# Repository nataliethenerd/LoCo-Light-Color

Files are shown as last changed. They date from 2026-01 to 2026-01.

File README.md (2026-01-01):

# LoCo (Light Color)





LoCo = Light Color. This project allows you to put a Game Boy Color in a Game Boy Light shell. Full Light colour PCB using the original parts. This board is made with modern screen kits in mind meaning it does not have the voltage rails for the original screen.

**ORDER AT 1MM WITH ENIG**

You can support me on Ko-Fi or by buying the board directly from me [my store](https://nataliethenerd.com/collections/all)

I also occasionally sell pre built PCBs on my store.



## Building

locoboardview

> [!WARNING]
> I am not responsible for your skill issues!

This board uses all the parts of an original Game Boy Color minus the IR and original screen circuit. Most parts are in the same spot, however if you are having trouble you can check the [interactive BOM](https://nataliethenerd.github.io/loco.html)

The thumbwheel circuit can be connected to an OSD screen to control brightness. The two touch pad wires and be connected to the pads labelled ↑↓ on the back top left side of the board. The select, A and B pads are easy connection pads for the screen also. 

screenguide

**My recommendations** 

- New power regulator like my [Safer Charge DC](https://nataliethenerd.com/products/safer-charge-dc)
- [Q5 OSD Game Boy Color screen](https://s.click.aliexpress.com/e/_DmvDS95). The OSD allows you to move the screen

**New parts**

- [Thumbwheel](https://s.click.aliexpress.com/e/_DFcsKf1)

## Update log:

Jan26: changed the CPU footprint to be a bit more forgiving

| Before | After |
| --- | ----- |
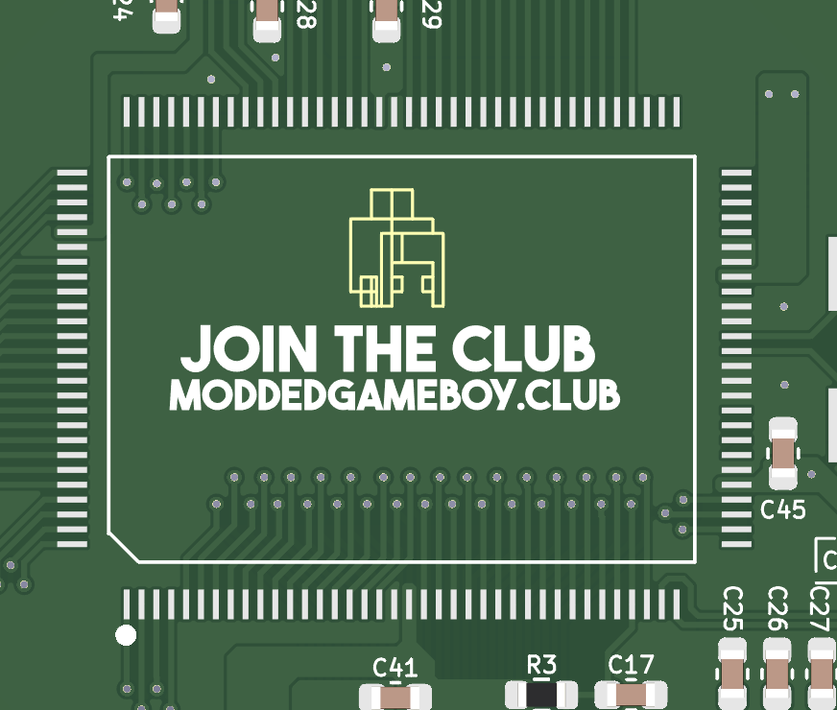
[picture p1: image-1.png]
old footprint
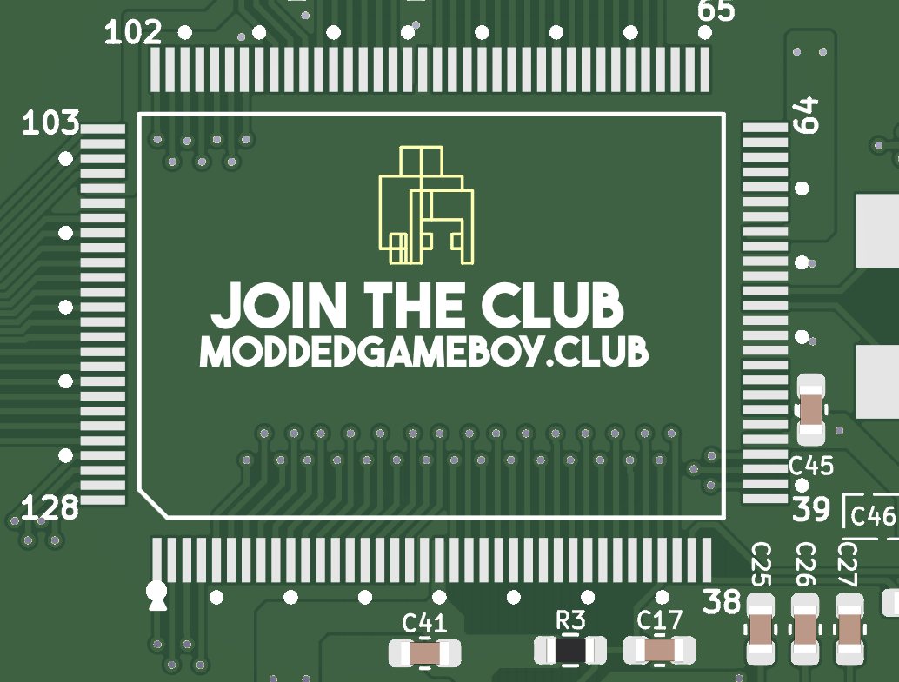
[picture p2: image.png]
new footprint
| |  |

## Thanks
- Hozy for the pushing me to do the first ever Light Color
- Console and Casks for the thumbwheel circuit

## Follow me

If you are into Game Boy modding or retro gaming, please consider using code "NatalieTheNerd" at:

• [Retro Modding](http://RetroModding.com) 

• [Retro Game Repair Shop](http://RetroGameRepairShop.com) 

• [Extreme Rate](http://ExtremeRate.com)

**My socials**

• [Twitter](https://twitter.com/natalie_thenerd) 

• [BlueSky](https://bsky.app/profile/nataliethenerd.com) 

• [Instagram](https://www.instagram.com/natalie.thenerd/) 

• [Modded Gameboy Club](https://moddedgameboy.club/) - a club dedicated to the modification of Game Boys, freely sharing resources

## License

Please do not remove my logo, website and name.



The CC BY-SA 4.0 (Creative Commons Attribution-ShareAlike 4.0 International) license allows you to:

1. **Share** - Copy and redistribute the material in any medium or format.
2. **Adapt** - Remix, transform, and build upon the material for any purpose, even commercially.

### Conditions:

- **Attribution** - You must give appropriate credit, provide a link to the license, and indicate if changes were made. You may do so in any reasonable manner, but not in any way that suggests the licensor endorses you or your use.
- **ShareAlike** - If you remix, transform, or build upon the material, you must distribute your contributions under the same license as the original.

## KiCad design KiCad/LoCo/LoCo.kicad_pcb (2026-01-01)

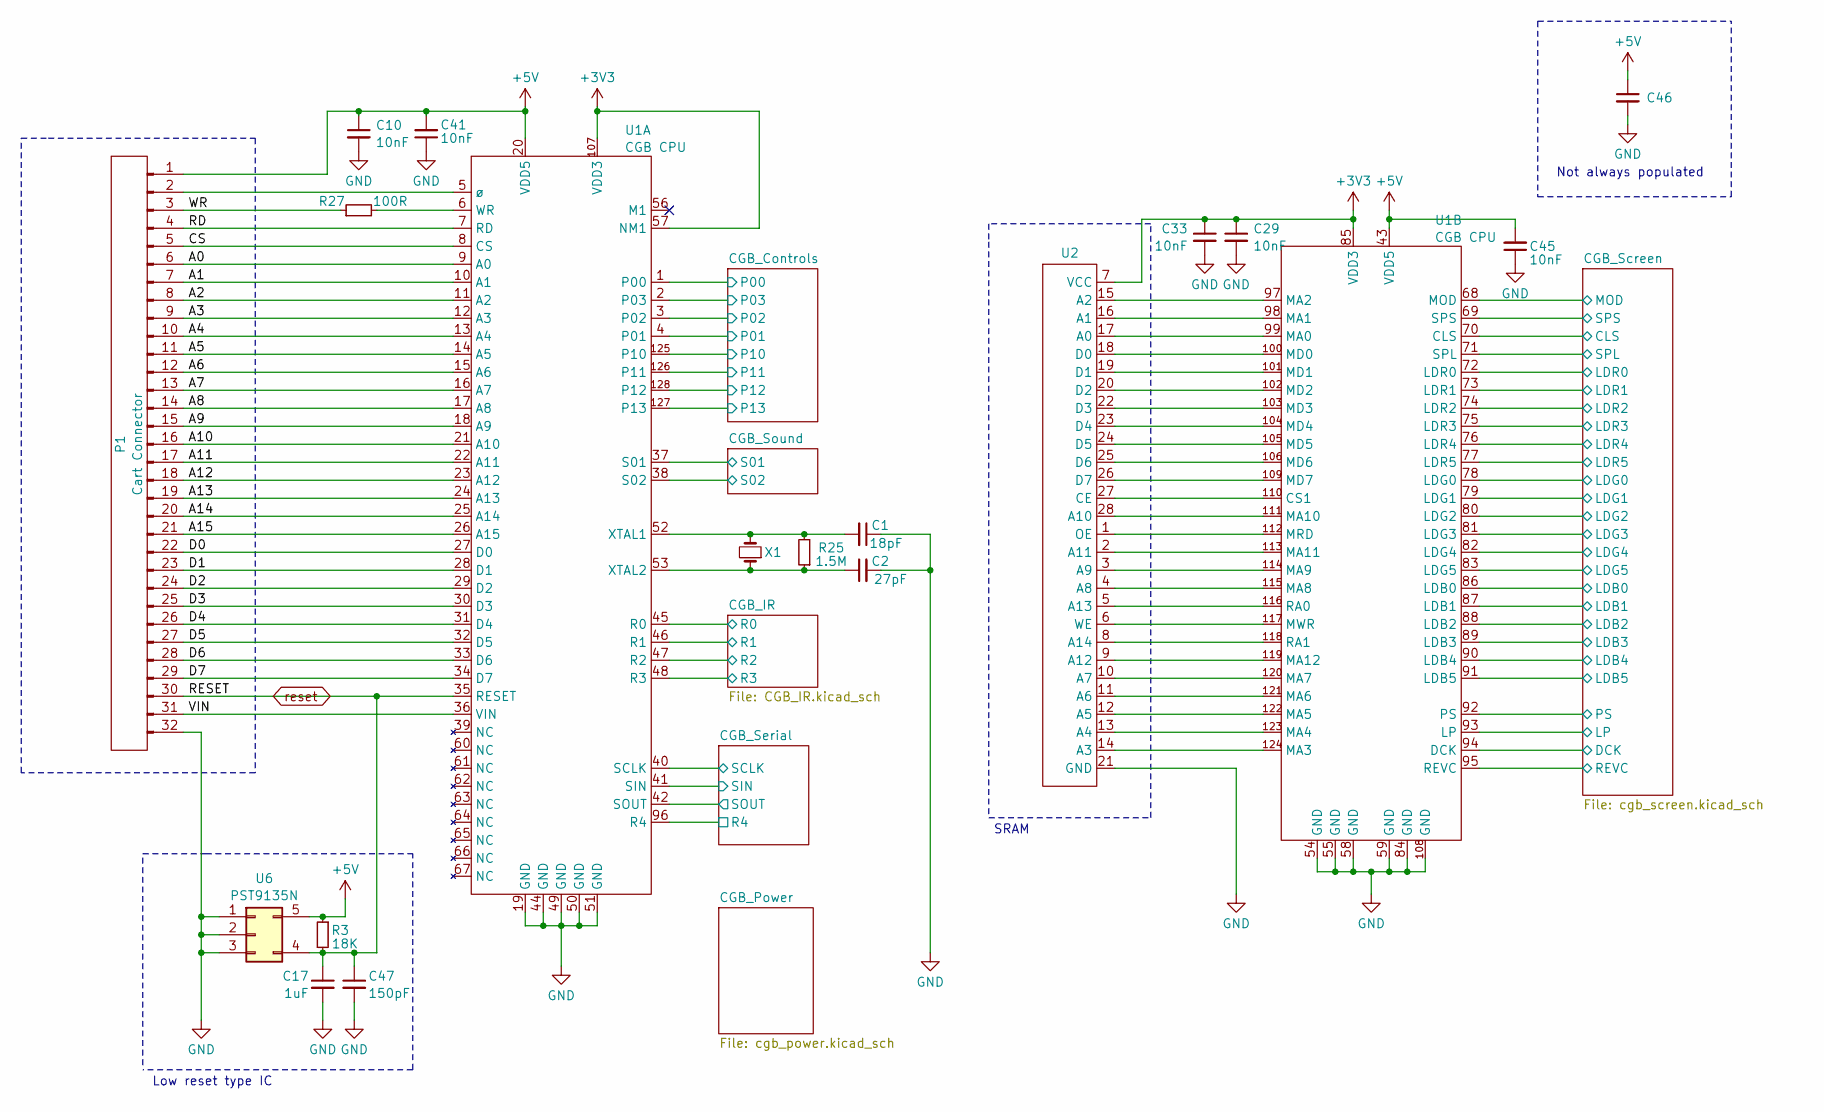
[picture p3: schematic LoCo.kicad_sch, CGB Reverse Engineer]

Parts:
C1: 18pF; C_0603_1608Metric
C2: 27pF; C_0603_1608Metric
C10, C29, C33, C41, C45: 10nF; C_0603_1608Metric
C17: 1uF; C_0603_1608Metric
C46: C_0603_1608Metric
C47: 150pF; C_0603_1608Metric
P1: Cart Connector; Cart CGB
R3: 18K; R_0603_1608Metric
R25: 1.5M; R_0603_1608Metric
R27: 100R; R_0603_1608Metric
U1: CGB CPU; CPU CGB
U2: TSOP-I-28_11.8x8mm_P0.55mm
U6: PST9135N; SOT-23-5
X1: Crystal_Small; Crystal CGB

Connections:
+3V3: C29.1, C33.1, U1.57 (NM1), U1.85 (VDD3), U1.107 (VDD3), U2.7 (VCC); also elsewhere on the board
+5V: C10.1, C41.2, C45.2, C46.1, P1.1, R3.1, U1.20 (VDD5), U1.43 (VDD5), U6.5; also elsewhere on the board
/A0: P1.6, U1.9 (A0)
/A1: P1.7, U1.10 (A1)
/A2: P1.8, U1.11 (A2)
/A3: P1.9, U1.12 (A3)
/A4: P1.10, U1.13 (A4)
/A5: P1.11, U1.14 (A5)
/A6: P1.12, U1.15 (A6)
/A7: P1.13, U1.16 (A7)
/A8: P1.14, U1.17 (A8)
/A9: P1.15, U1.18 (A9)
/A10: P1.16, U1.21 (A10)
/A11: P1.17, U1.22 (A11)
/A12: P1.18, U1.23 (A12)
/A13: P1.19, U1.24 (A13)
/A14: P1.20, U1.25 (A14)
/A15: P1.21, U1.26 (A15)
/CGB_Controls/P00: U1.1 (P00); also elsewhere on the board
/CGB_Controls/P01: U1.4 (P01); also elsewhere on the board
/CGB_Controls/P02: U1.3 (P02); also elsewhere on the board
/CGB_Controls/P03: U1.2 (P03); also elsewhere on the board
/CGB_Controls/P10: U1.125 (P10); also elsewhere on the board
/CGB_Controls/P11: U1.126 (P11); also elsewhere on the board
/CGB_Controls/P12: U1.128 (P12); also elsewhere on the board
/CGB_Controls/P13: U1.127 (P13); also elsewhere on the board
/CGB_Screen/CLS: U1.70 (CLS); also elsewhere on the board
/CGB_Screen/DCK: U1.94 (DCK); also elsewhere on the board
/CGB_Screen/LDB0: U1.86 (LDB0); also elsewhere on the board
/CGB_Screen/LDB1: U1.87 (LDB1); also elsewhere on the board
/CGB_Screen/LDB2: U1.88 (LDB2); also elsewhere on the board
/CGB_Screen/LDB3: U1.89 (LDB3); also elsewhere on the board
/CGB_Screen/LDB4: U1.90 (LDB4); also elsewhere on the board
/CGB_Screen/LDB5: U1.91 (LDB5); also elsewhere on the board
/CGB_Screen/LDG0: U1.78 (LDG0); also elsewhere on the board
/CGB_Screen/LDG1: U1.79 (LDG1); also elsewhere on the board
/CGB_Screen/LDG2: U1.80 (LDG2); also elsewhere on the board
/CGB_Screen/LDG3: U1.81 (LDG3); also elsewhere on the board
/CGB_Screen/LDG4: U1.82 (LDG4); also elsewhere on the board
/CGB_Screen/LDG5: U1.83 (LDG5); also elsewhere on the board
/CGB_Screen/LDR0: U1.72 (LDR0); also elsewhere on the board
/CGB_Screen/LDR1: U1.73 (LDR1); also elsewhere on the board
/CGB_Screen/LDR2: U1.74 (LDR2); also elsewhere on the board
/CGB_Screen/LDR3: U1.75 (LDR3); also elsewhere on the board
/CGB_Screen/LDR4: U1.76 (LDR4); also elsewhere on the board
/CGB_Screen/LDR5: U1.77 (LDR5); also elsewhere on the board
/CGB_Screen/LP: U1.93 (LP); also elsewhere on the board
/CGB_Screen/MOD: U1.68 (MOD); also elsewhere on the board
/CGB_Screen/PS: U1.92 (PS); also elsewhere on the board
/CGB_Screen/SPL: U1.71 (SPL); also elsewhere on the board
/CGB_Screen/SPS: U1.69 (SPS); also elsewhere on the board
/CGB_Serial/R4: U1.96 (R4); also elsewhere on the board
/CGB_Serial/SCLK: U1.40 (SCLK); also elsewhere on the board
/CGB_Serial/SIN: U1.41 (SIN); also elsewhere on the board
/CGB_Serial/SOUT: U1.42 (SOUT); also elsewhere on the board
/CGB_Sound/S01: U1.37 (S01); also elsewhere on the board
/CGB_Sound/S02: U1.38 (S02); also elsewhere on the board
/CS: P1.5, U1.8 (CS)
/D0: P1.22, U1.27 (D0)
/D1: P1.23, U1.28 (D1)
/D2: P1.24, U1.29 (D2)
/D3: P1.25, U1.30 (D3)
/D4: P1.26, U1.31 (D4)
/D5: P1.27, U1.32 (D5)
/D6: P1.28, U1.33 (D6)
/D7: P1.29, U1.34 (D7)
/R0: U1.45 (R0)
/R1: U1.46 (R1)
/R2: U1.47 (R2)
/R3: U1.48 (R3)
/RD: P1.4, U1.7 (RD)
/REVC: U1.95 (REVC)
/VIN: P1.31, U1.36 (VIN)
/WR: P1.3, R27.1
GND: C1.1, C2.2, C10.2, C17.2, C29.2, C33.2, C41.1, C45.1, C46.2, C47.2, P1.32, U1.19 (GND), U1.44 (GND), U1.49 (GND), U1.50 (GND), U1.51 (GND), U1.54 (GND), U1.55 (GND), U1.58 (GND), U1.59 (GND), U1.84 (GND), U1.108 (GND), U2.21 (GND), U6.1, U6.2, U6.3; also elsewhere on the board
unnamed: P1.2, U1.5 (ø)
unnamed: R27.2, U1.6 (WR)
unnamed: C1.2, R25.2, U1.52 (XTAL1), X1.2
unnamed: C2.1, R25.1, U1.53 (XTAL2), X1.1
unnamed: U1.110 (CS1), U2.27 (CE)
unnamed: U1.99 (MA0), U2.17 (A0)
unnamed: U1.98 (MA1), U2.16 (A1)
unnamed: U1.97 (MA2), U2.15 (A2)
unnamed: U1.124 (MA3), U2.14 (A3)
unnamed: U1.123 (MA4), U2.13 (A4)
unnamed: U1.122 (MA5), U2.12 (A5)
unnamed: U1.121 (MA6), U2.11 (A6)
unnamed: U1.120 (MA7), U2.10 (A7)
unnamed: U1.115 (MA8), U2.4 (A8)
unnamed: U1.114 (MA9), U2.3 (A9)
unnamed: U1.111 (MA10), U2.28 (A10)
unnamed: U1.113 (MA11), U2.2 (A11)
unnamed: U1.119 (MA12), U2.9 (A12)
unnamed: U1.100 (MD0), U2.18 (D0)
unnamed: U1.101 (MD1), U2.19 (D1)
unnamed: U1.102 (MD2), U2.20 (D2)
unnamed: U1.103 (MD3), U2.22 (D3)
unnamed: U1.104 (MD4), U2.23 (D4)
unnamed: U1.105 (MD5), U2.24 (D5)
unnamed: U1.106 (MD6), U2.25 (D6)
unnamed: U1.109 (MD7), U2.26 (D7)
unnamed: U1.112 (MRD), U2.1 (OE)
unnamed: U1.117 (MWR), U2.6 (WE)
unnamed: U1.116 (RA0), U2.5 (A13)
unnamed: U1.118 (RA1), U2.8 (A14)
reset: C17.1, C47.1, P1.30, R3.2, U1.35 (RESET), U6.4; also elsewhere on the board

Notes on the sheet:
Not always populated
Low reset type IC
SRAM

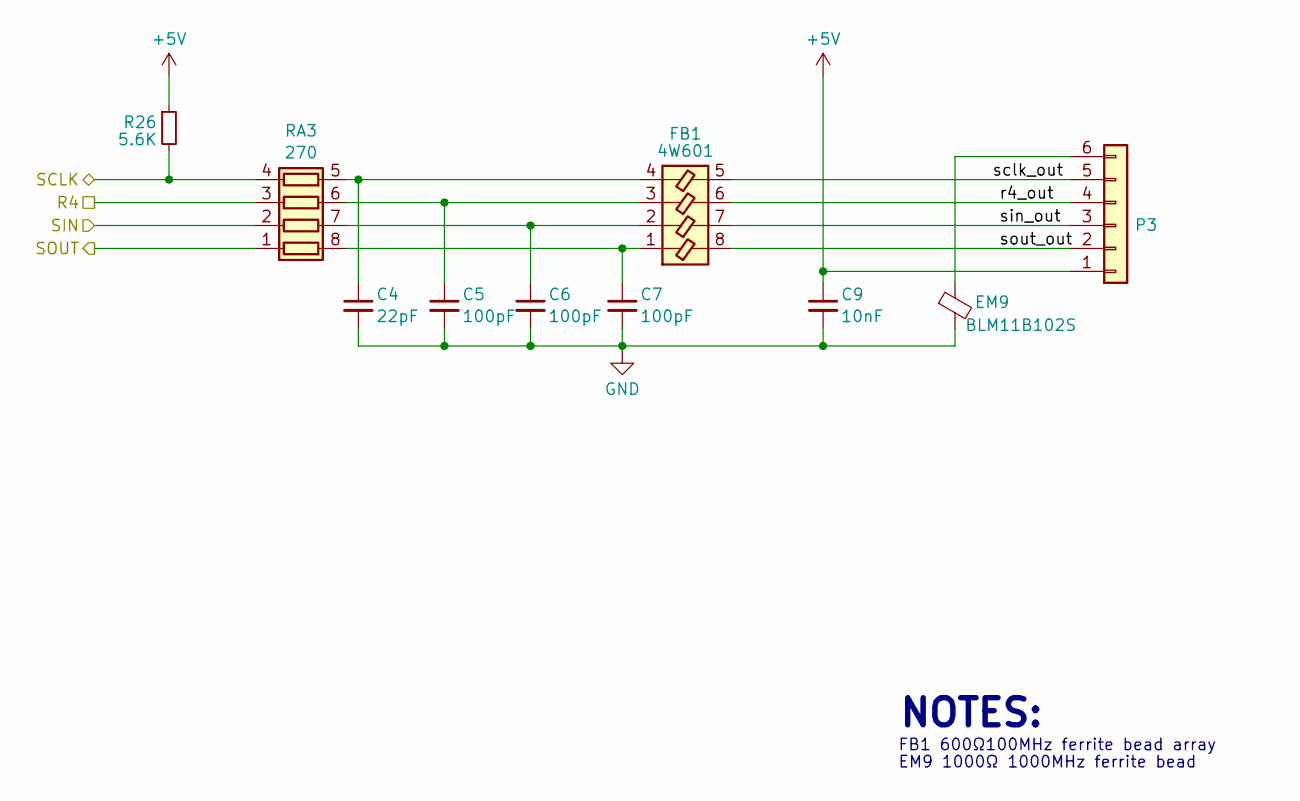
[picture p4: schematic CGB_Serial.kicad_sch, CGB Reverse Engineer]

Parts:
C4: 22pF; C_0603_1608Metric
C5, C6, C7: 100pF; C_0603_1608Metric
C9: 10nF; C_0603_1608Metric
EM9: BLM11B102S; R_0603_1608Metric
FB1: 4W601; R_Array_Concave_4x0603
P3: Conn_01x06; Serial CGB
R26: 5.6K; R_0603_1608Metric
RA3: 270; R_Array_Concave_4x0603

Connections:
+5V: C9.1, P3.1, R26.1; also elsewhere on the board
/CGB_Serial/R4: RA3.3 (R3.1); also elsewhere on the board
/CGB_Serial/SCLK: R26.2, RA3.4 (R4.1); also elsewhere on the board
/CGB_Serial/SIN: RA3.2 (R2.1); also elsewhere on the board
/CGB_Serial/SOUT: RA3.1 (R1.1); also elsewhere on the board
/CGB_Serial/r4_out: FB1.6, P3.4
/CGB_Serial/sclk_out: FB1.5, P3.5
/CGB_Serial/sin_out: FB1.7, P3.3
/CGB_Serial/sout_out: FB1.8, P3.2
GND: C4.2, C5.2, C6.2, C7.2, C9.2, EM9.2; also elsewhere on the board
unnamed: EM9.1, P3.6
unnamed: C7.1, FB1.1, RA3.8 (R1.2)
unnamed: C6.1, FB1.2, RA3.7 (R2.2)
unnamed: C5.1, FB1.3, RA3.6 (R3.2)
unnamed: C4.1, FB1.4, RA3.5 (R4.2)

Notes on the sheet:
EM9 1000Ω 1000MHz ferrite bead
FB1 600Ω100MHz ferrite bead array
NOTES:

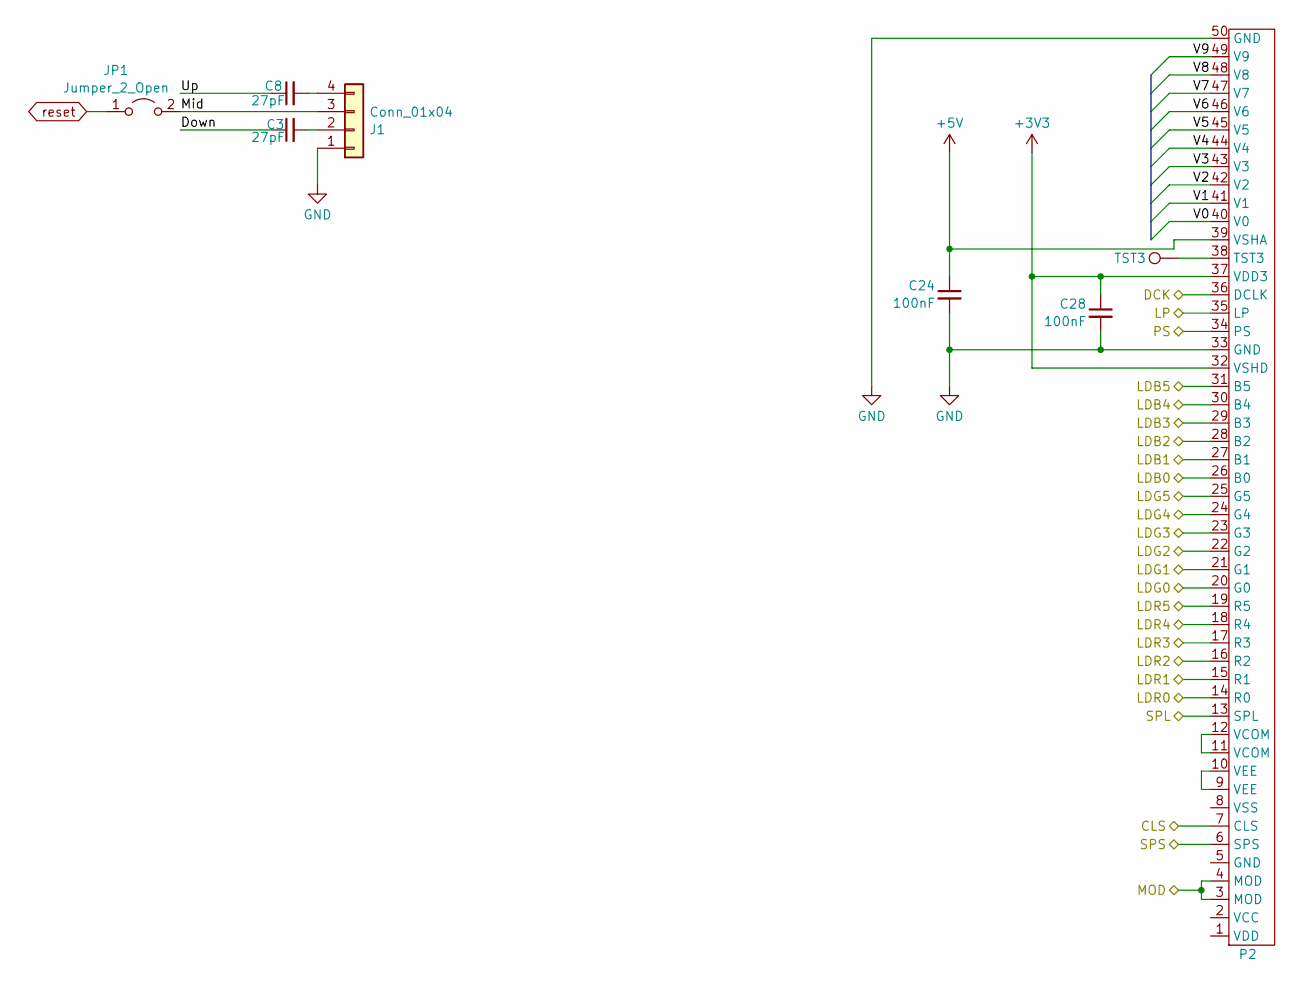
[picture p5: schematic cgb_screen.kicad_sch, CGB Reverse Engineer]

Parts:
C3, C8: 27pF; R_0603_1608Metric
C24, C28: 100nF; C_0603_1608Metric
J1: Conn_01x04; Thumbwheel toggle switch
JP1: Jumper_2_Open; SolderJumper-2_P1.3mm_Open_RoundedPad1.0x1.5mm
P2: Screen CGB
TST3: TestPoint

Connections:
+3V3: C28.1, P2.32 (VSHD), P2.37 (VDD3); also elsewhere on the board
+5V: C24.1, P2.39 (VSHA); also elsewhere on the board
/CGB_Screen/CLS: P2.7 (CLS); also elsewhere on the board
/CGB_Screen/DCK: P2.36 (DCLK); also elsewhere on the board
/CGB_Screen/Down: C3.1
/CGB_Screen/LDB0: P2.26 (B0); also elsewhere on the board
/CGB_Screen/LDB1: P2.27 (B1); also elsewhere on the board
/CGB_Screen/LDB2: P2.28 (B2); also elsewhere on the board
/CGB_Screen/LDB3: P2.29 (B3); also elsewhere on the board
/CGB_Screen/LDB4: P2.30 (B4); also elsewhere on the board
/CGB_Screen/LDB5: P2.31 (B5); also elsewhere on the board
/CGB_Screen/LDG0: P2.20 (G0); also elsewhere on the board
/CGB_Screen/LDG1: P2.21 (G1); also elsewhere on the board
/CGB_Screen/LDG2: P2.22 (G2); also elsewhere on the board
/CGB_Screen/LDG3: P2.23 (G3); also elsewhere on the board
/CGB_Screen/LDG4: P2.24 (G4); also elsewhere on the board
/CGB_Screen/LDG5: P2.25 (G5); also elsewhere on the board
/CGB_Screen/LDR0: P2.14 (R0); also elsewhere on the board
/CGB_Screen/LDR1: P2.15 (R1); also elsewhere on the board
/CGB_Screen/LDR2: P2.16 (R2); also elsewhere on the board
/CGB_Screen/LDR3: P2.17 (R3); also elsewhere on the board
/CGB_Screen/LDR4: P2.18 (R4); also elsewhere on the board
/CGB_Screen/LDR5: P2.19 (R5); also elsewhere on the board
/CGB_Screen/LP: P2.35 (LP); also elsewhere on the board
/CGB_Screen/MOD: P2.3 (MOD), P2.4 (MOD); also elsewhere on the board
/CGB_Screen/Mid: J1.3, JP1.2 (B)
/CGB_Screen/PS: P2.34 (PS); also elsewhere on the board
/CGB_Screen/SPL: P2.13 (SPL); also elsewhere on the board
/CGB_Screen/SPS: P2.6 (SPS); also elsewhere on the board
/CGB_Screen/Up: C8.1
/CGB_Screen/V0: P2.40 (V0)
/CGB_Screen/V1: P2.41 (V1)
/CGB_Screen/V2: P2.42 (V2)
/CGB_Screen/V3: P2.43 (V3)
/CGB_Screen/V4: P2.44 (V4)
/CGB_Screen/V5: P2.45 (V5)
/CGB_Screen/V6: P2.46 (V6)
/CGB_Screen/V7: P2.47 (V7)
/CGB_Screen/V8: P2.48 (V8)
/CGB_Screen/V9: P2.49 (V9)
GND: C24.2, C28.2, J1.1, P2.33 (GND), P2.50 (GND); also elsewhere on the board
unnamed: C3.2, J1.2
unnamed: C8.2, J1.4
unnamed: P2.38 (TST3), TST3.1
unnamed: P2.11 (VCOM), P2.12 (VCOM)
unnamed: P2.9 (VEE), P2.10 (VEE)
reset: JP1.1 (A); also elsewhere on the board

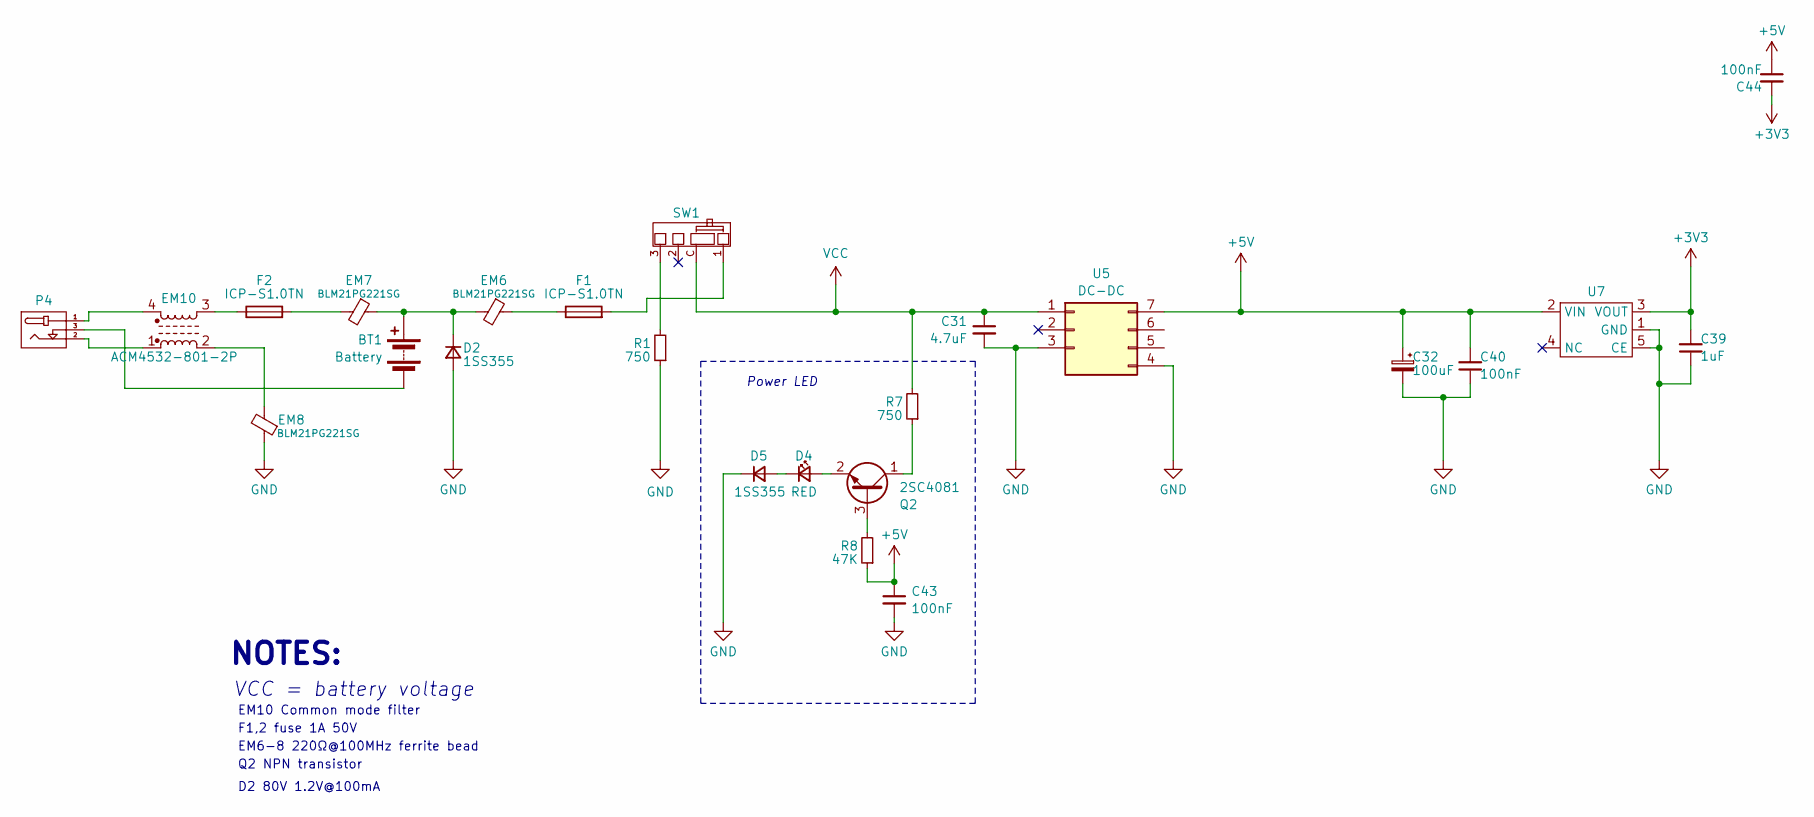
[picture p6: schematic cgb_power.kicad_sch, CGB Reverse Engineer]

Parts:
BT1: Battery; Battery CGB
C31: 4.7uF; C_0603_1608Metric
C32: 100uF; CP_Elec_6.3x5.4
C39: 1uF; C_0603_1608Metric
C40, C43, C44: 100nF; C_0603_1608Metric
D2, D5: 1SS355; D_SOD-323_HandSoldering
D4: RED; LED_D3.0mm
EM6, EM7, EM8: BLM21PG221SG; R_0805_2012Metric
EM10: ACM4532-801-2P; Crystal_SMD_EuroQuartz_MJ-4Pin_5.0x3.2mm
F1, F2: ICP-S1.0TN; Fuse_1206_3216Metric_Pad1.42x1.75mm_HandSolder
P4: DCJACK
Q2: 2SC4081; SOT-323_SC-70
R1, R7: 750; R_0603_1608Metric
R8: 47K; R_0603_1608Metric
SW1: Switch CGB
U5: DC-DC; DC
U7: SOT-23-5

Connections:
+3V3: C39.2, C44.2, U7.3 (VOUT); also elsewhere on the board
+5V: C32.1, C40.2, C43.1, C44.1, R8.1, U5.7, U7.2 (VIN); also elsewhere on the board
GND: C31.2, C32.2, C39.1, C40.1, C43.2, D2.2 (A), D5.1 (K), EM8.1, R1.1, U5.3, U5.4, U7.1 (GND), U7.5 (CE); also elsewhere on the board
unnamed: BT1.1 (+), D2.1 (K), EM6.2, EM7.1
unnamed: BT1.2 (-), P4.3
unnamed: D4.2 (A), Q2.2 (B)
unnamed: D4.1 (K), D5.2 (A)
unnamed: EM6.1, F1.1
unnamed: EM7.2, F2.2
unnamed: EM10.1, P4.2
unnamed: EM8.2, EM10.2
unnamed: EM10.3, F2.1
unnamed: EM10.4, P4.1
unnamed: F1.2, SW1.1
unnamed: Q2.3 (C), R8.2
unnamed: Q2.1 (E), R7.1
unnamed: R1.2, SW1.3
VCC: C31.1, R7.2, SW1.C, U5.1; also elsewhere on the board

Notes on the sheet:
NOTES:
D2 80V 1.2V@100mA
EM6-8 220Ω@100MHz ferrite bead
EM10 Common mode filter
F1,2 fuse 1A 50V
Power LED
Q2 NPN transistor
VCC = battery voltage

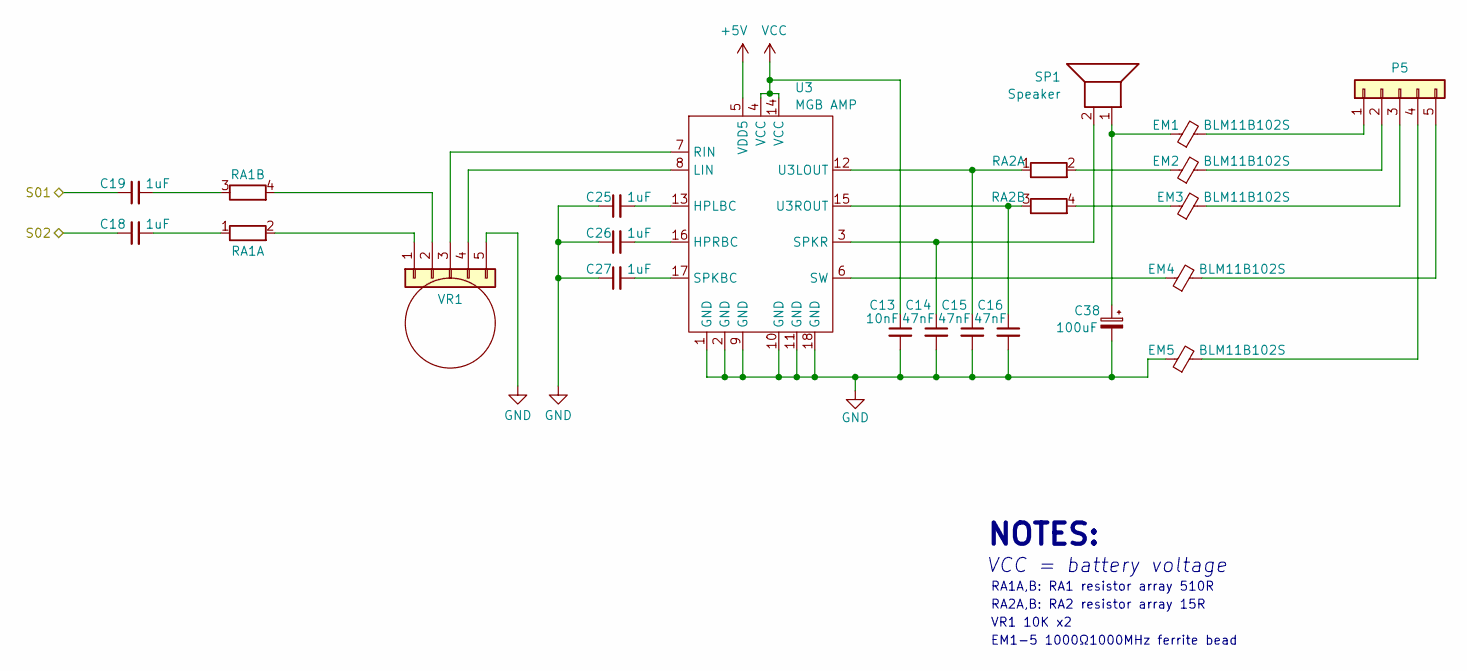
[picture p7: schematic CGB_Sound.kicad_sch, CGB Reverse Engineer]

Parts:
C13: 10nF; C_0603_1608Metric
C14, C15, C16: 47nF; C_0603_1608Metric
C18, C19, C25, C26, C27: 1uF; C_0603_1608Metric
C38: 100uF; CP_Elec_5x5.3
EM1, EM2, EM3, EM4, EM5: BLM11B102S; R_0603_1608Metric
P5: Conn_01x05; HPjack
RA1, RA2: R_Pack02_SIP_Split; R_Array_Concave_2x0603
SP1: Speaker; TestPoint_2Pads_Pitch2.54mm_Drill0.8mm
U3: MGB AMP; Amp MGB
VR1: Conn_01x05; Volume wheel CGB

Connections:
+5V: U3.5 (VDD5); also elsewhere on the board
/CGB_Sound/S01: C19.1; also elsewhere on the board
/CGB_Sound/S02: C18.1; also elsewhere on the board
GND: C13.2, C14.2, C15.2, C16.2, C25.1, C26.1, C27.1, C38.2, EM5.1, U3.1 (GND), U3.2 (GND), U3.9 (GND), U3.10 (GND), U3.11 (GND), U3.18 (GND), VR1.5; also elsewhere on the board
unnamed: C38.1, EM1.1, SP1.1
unnamed: EM1.2, P5.1
unnamed: EM2.2, P5.2
unnamed: EM3.2, P5.3
unnamed: EM5.2, P5.4
unnamed: EM4.2, P5.5
unnamed: C18.2, RA1.1 (R1.1)
unnamed: RA1.2 (R1.2), VR1.1
unnamed: C19.2, RA1.3 (R2.1)
unnamed: RA1.4 (R2.2), VR1.2
unnamed: C15.1, RA2.1 (R1.1), U3.12 (U3LOUT)
unnamed: EM2.1, RA2.2 (R1.2)
unnamed: C16.1, RA2.3 (R2.1), U3.15 (U3ROUT)
unnamed: EM3.1, RA2.4 (R2.2)
unnamed: C25.2, U3.13 (HPLBC)
unnamed: C26.2, U3.16 (HPRBC)
unnamed: U3.8 (LIN), VR1.4
unnamed: U3.7 (RIN), VR1.3
unnamed: C27.2, U3.17 (SPKBC)
unnamed: C14.1, SP1.2, U3.3 (SPKR)
unnamed: EM4.1, U3.6 (SW)
VCC: C13.1, U3.4 (VCC), U3.14 (VCC); also elsewhere on the board

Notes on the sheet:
EM1-5 1000Ω1000MHz ferrite bead
RA1A,B: RA1 resistor array 510R
VR1 10K x2
VCC = battery voltage
NOTES:
RA2A,B: RA2 resistor array 15R

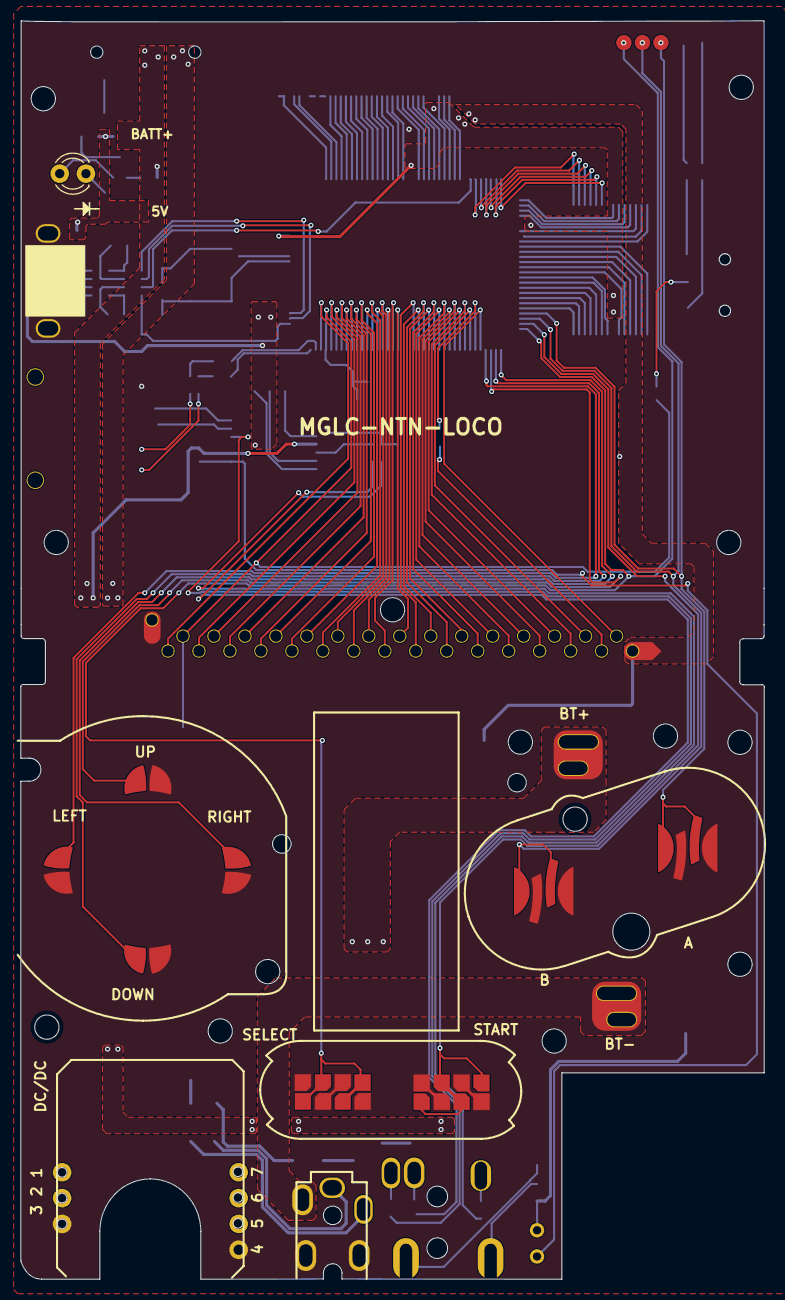
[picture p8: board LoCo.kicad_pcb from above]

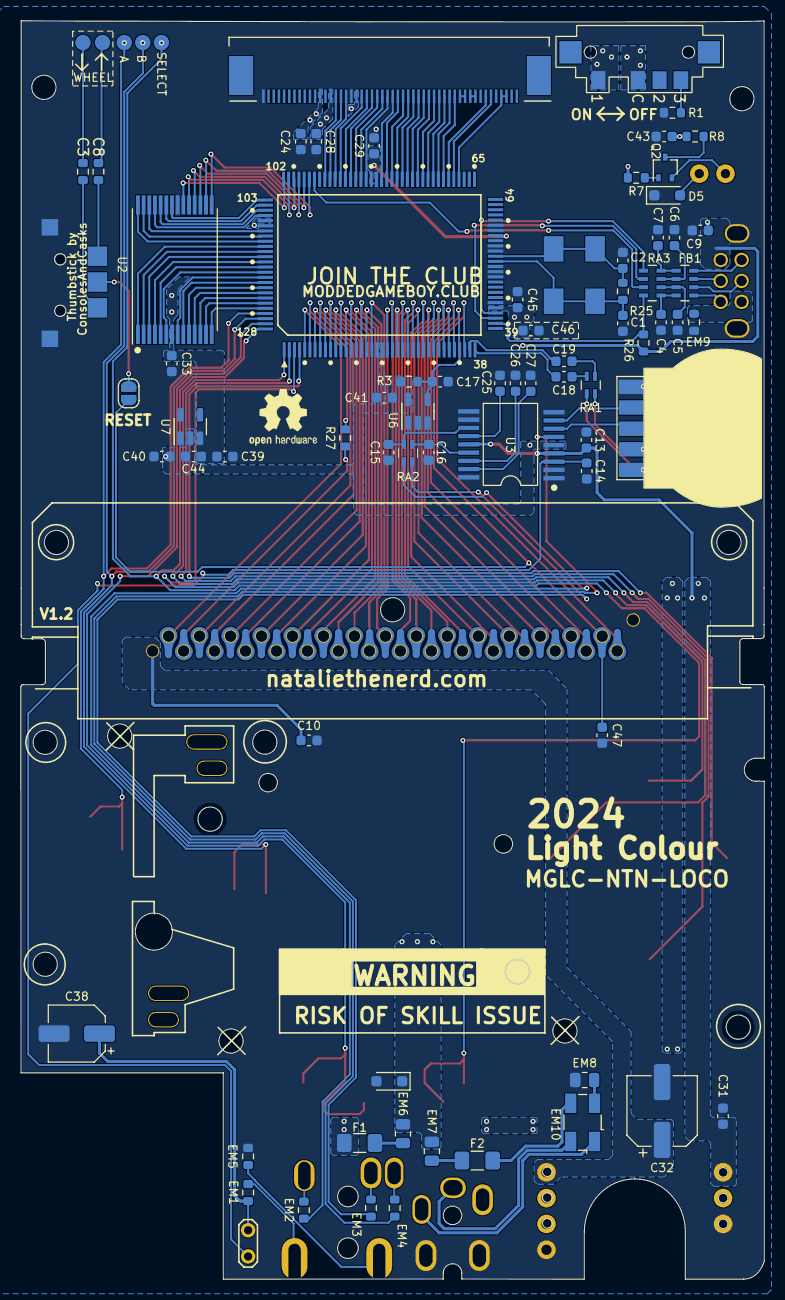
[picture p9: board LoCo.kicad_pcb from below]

Board: 2 copper layers, 72.0 x 121.9 mm, 88 parts (73 on the bottom side), 151 nets.

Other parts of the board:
SW2: Right; Dpad CGB
SW3: Down; Dpad CGB
SW4: Up; Dpad CGB
SW5: Left; Dpad CGB
SW6: A; AB CGB
SW7: B; AB CGB
SW8: Select; Select CGB
SW9: Start; Start CGB

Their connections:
/CGB_Controls/P00: SW2.2; also elsewhere on the board
/CGB_Controls/P01: SW5.1; also elsewhere on the board
/CGB_Controls/P02: SW4.2; also elsewhere on the board
/CGB_Controls/P03: SW3.1; also elsewhere on the board
/CGB_Controls/P10: SW6.2; also elsewhere on the board
/CGB_Controls/P11: SW7.2; also elsewhere on the board
/CGB_Controls/P12: SW8.2; also elsewhere on the board
/CGB_Controls/P13: SW9.2; also elsewhere on the board
GND: SW2.1, SW3.2, SW4.1, SW5.2, SW6.1, SW7.1, SW8.1, SW9.1; also elsewhere on the board

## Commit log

2024-12-22 first push
    [CGB_IR.kicad_sch, CGB_Serial.kicad_sch, CGB_Sound.kicad_sch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]
2026-01-01 changed cpu footprint
    [LoCo.kicad_pcb]
